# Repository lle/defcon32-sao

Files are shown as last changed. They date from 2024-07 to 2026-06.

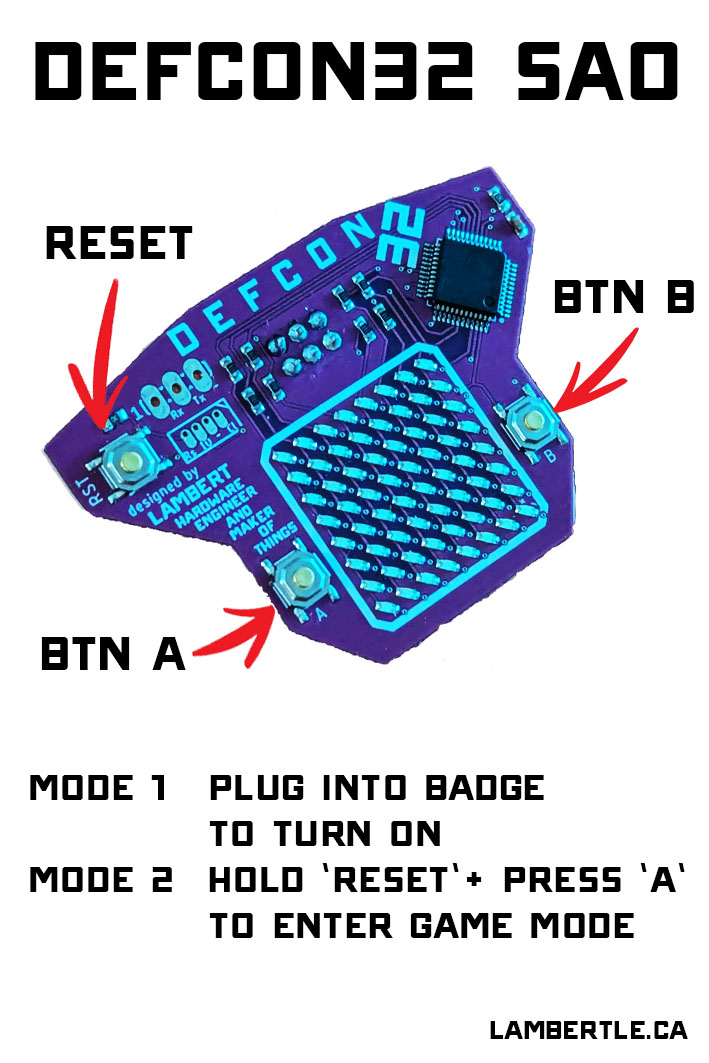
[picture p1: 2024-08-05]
media/defcon32-sao.jpg

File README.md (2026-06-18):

## Firmware Structure
See this readme in this repo: [SAO31](https://github.com/lle/defcon31-addon)
The foundation firmware is from my SAO from last year. This year's firmware adds an the Racing game mode in addition to the animation/screensaver mode.

## How to Flash
Things you need:
* ST-Link - I personally use an STM32F0 Nucleo Board: [497-15096-ND](https://www.digikey.ca/en/products/detail/stmicroelectronics/NUCLEO-F072RB/5047984)
* Female Connector: [H2193-ND](https://www.digikey.ca/en/products/detail/hirose-electric-co-ltd/DF13-4P-1-25DSA/241767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)
* Male Connector: [H2181-ND](https://www.digikey.ca/en/products/detail/hirose-electric-co-ltd/DF13-4S-1-25C/241750)
* Precrimped wires x4: [H4BXG-10112-B8-ND](https://www.digikey.ca/en/products/detail/hirose-electric-co-ltd/H4BXG-10112-B8/426117)

### Instruction
* Connect the ST-Link SWD header to the PCB's programming port
connection

* Compile the code in STM CubeIDE: "Project"->"Build All"
* Connect your Nucleo board to your computer
* Configure the debugger as follows: "Run" -> "Debug Configurations"
connection
* Flash the firmware: "Run" -> "Run"
* You will see this in the logs
```
Memory Programming ...
Opening and parsing file: ST-LINK_GDB_server_a15460.srec
  File          : ST-LINK_GDB_server_a15460.srec
  Size          : 21.34 KB 
  Address       : 0x08000000 
Erasing memory corresponding to segment 0:
Erasing internal memory sectors [0 21]
Download in Progress:
File download complete
Time elapsed during download operation: 00:00:01.454
Verifying ...
Download verified successfully 
Shutting down...
Exit.
```
https://github.com/lle/defcon31-addon

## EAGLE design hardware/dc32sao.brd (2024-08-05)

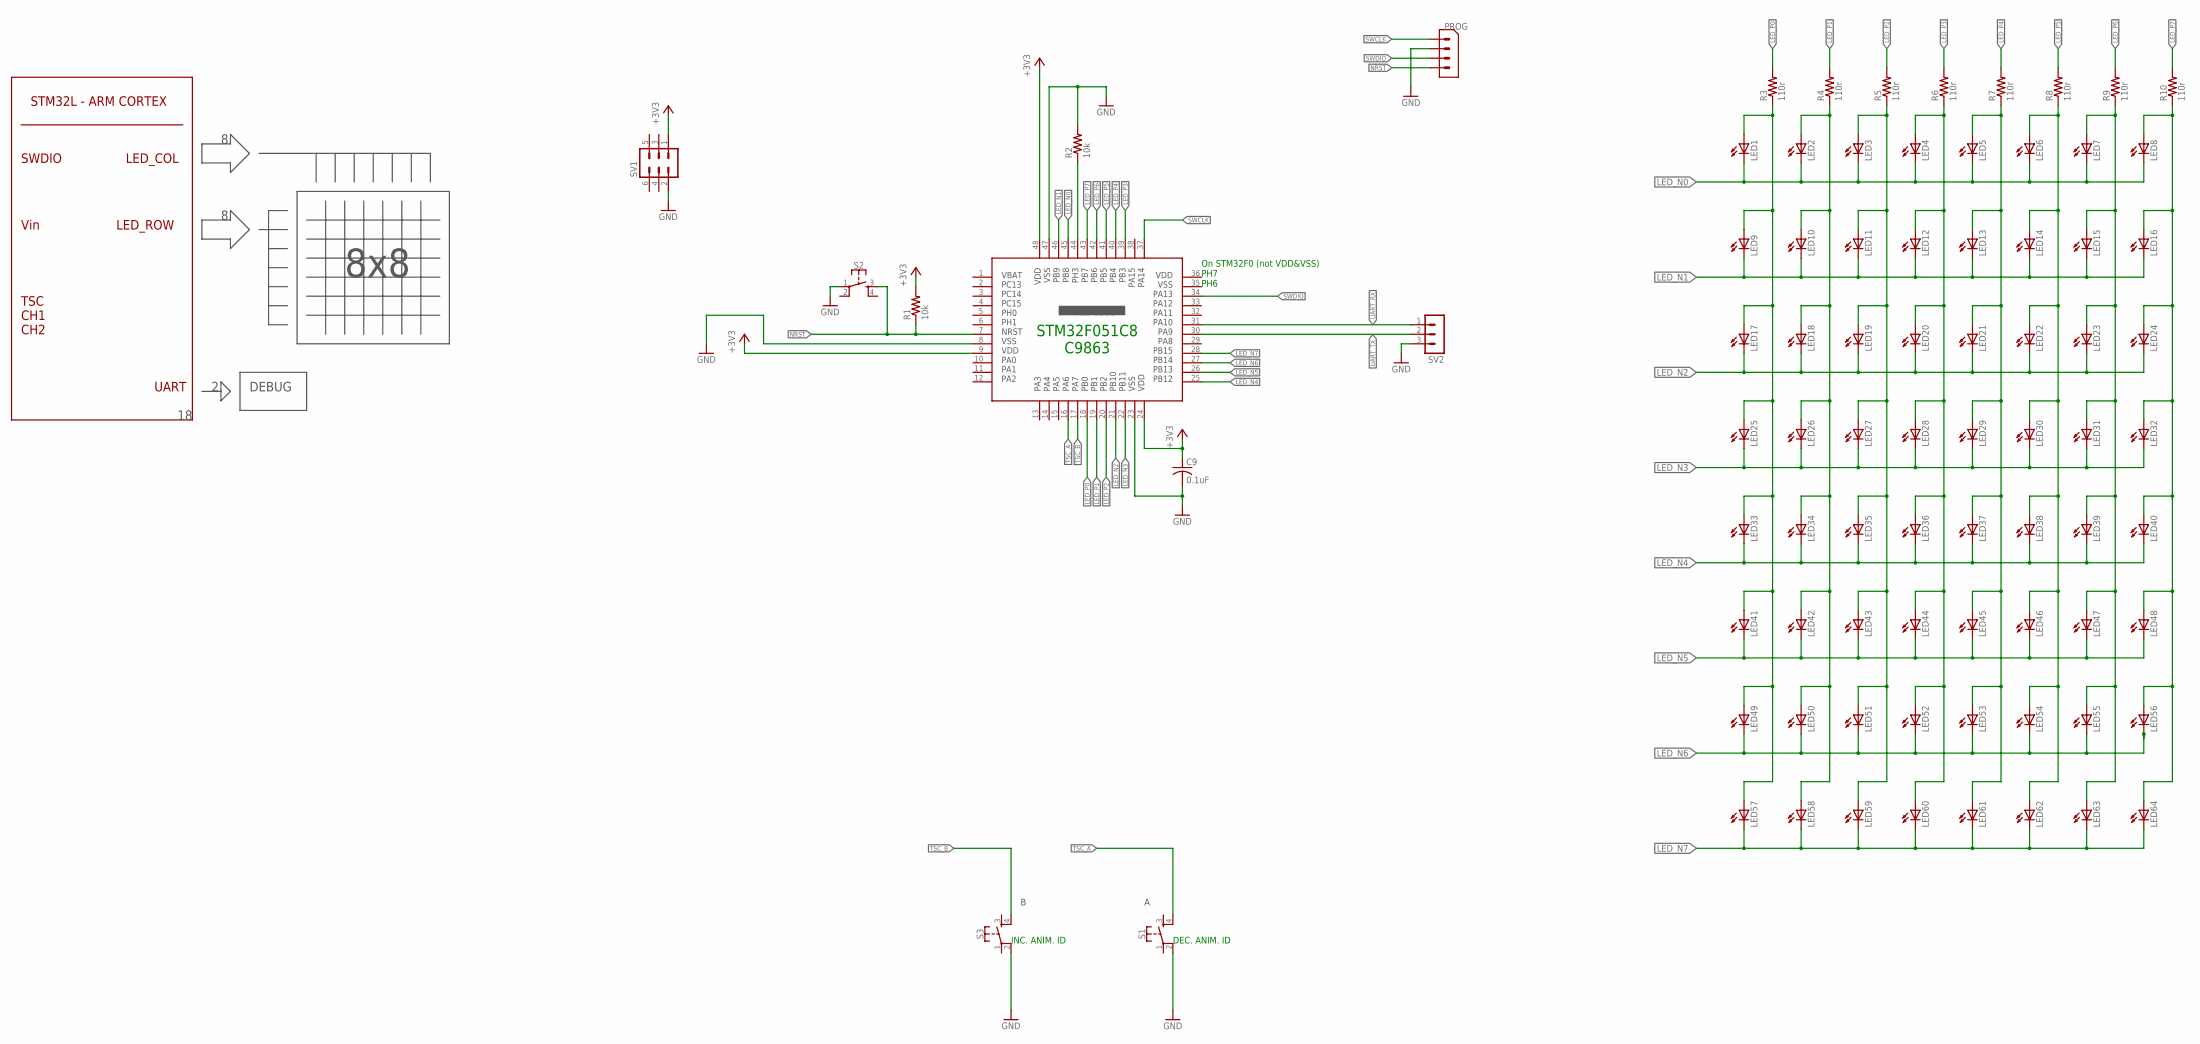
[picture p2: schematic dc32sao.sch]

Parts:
C9: 0.1uF; C0603
LED1, LED2, LED3, LED4, LED5, LED6, LED7, LED8, LED9, LED10, LED11, LED12, LED13, LED14, LED15, LED16, LED17, LED18, LED19, LED20, LED21, LED22, LED23, LED24, LED25, LED26, LED27, LED28, LED29, LED30, LED31, LED32, LED33, LED34, LED35, LED36, LED37, LED38, LED39, LED40, LED41, LED42, LED43, LED44, LED45, LED46, LED47, LED48, LED49, LED50, LED51, LED52, LED53, LED54, LED55, LED56, LED57, LED58, LED59, LED60, LED61, LED62, LED63, LED64: LEDCHIP-LED0603; CHIP-LED0603
PROG: 4-PIN-1.25MM
R1, R2: 10k; R0603
R3, R4, R5, R6, R7, R8, R9, R10: 110r; R0603
S1, S2, S3: MOMENTARY-SWITCH-SPST-2-SMD-5.2MM; TACTILE_SWITCH_SMD_5.2MM
SV1: MA03-2
SV2: MA03-1
U$2: STM32L431CC; QFP50P900X900X160-48

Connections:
+3V3: C9.1, R1.2, SV1.1, U$2.9, U$2.24, U$2.48
GND: C9.2, PROG.P$3 (2), R2.2, S1.2, S2.1, S3.2, SV1.2, SV2.3, U$2.8, U$2.23, U$2.47
LED_N0: LED1.C, LED2.C, LED3.C, LED4.C, LED5.C, LED6.C, LED7.C, LED8.C, U$2.45
LED_N1: LED9.C, LED10.C, LED11.C, LED12.C, LED13.C, LED14.C, LED15.C, LED16.C, U$2.46
LED_N2: LED17.C, LED18.C, LED19.C, LED20.C, LED21.C, LED22.C, LED23.C, LED24.C, U$2.21
LED_N3: LED25.C, LED26.C, LED27.C, LED28.C, LED29.C, LED30.C, LED31.C, LED32.C, U$2.22
LED_N4: LED33.C, LED34.C, LED35.C, LED36.C, LED37.C, LED38.C, LED39.C, LED40.C, U$2.25
LED_N5: LED41.C, LED42.C, LED43.C, LED44.C, LED45.C, LED46.C, LED47.C, LED48.C, U$2.26
LED_N6: LED49.C, LED50.C, LED51.C, LED52.C, LED53.C, LED54.C, LED55.C, LED56.C, U$2.27
LED_N7: LED57.C, LED58.C, LED59.C, LED60.C, LED61.C, LED62.C, LED63.C, LED64.C, U$2.28
LED_P0: R3.2, U$2.18
LED_P0B: LED1.A, LED9.A, LED17.A, LED25.A, LED33.A, LED41.A, LED49.A, LED57.A, R3.1
LED_P1: R4.2, U$2.19
LED_P1B: LED2.A, LED10.A, LED18.A, LED26.A, LED34.A, LED42.A, LED50.A, LED58.A, R4.1
LED_P2: R5.2, U$2.20
LED_P2B: LED3.A, LED11.A, LED19.A, LED27.A, LED35.A, LED43.A, LED51.A, LED59.A, R5.1
LED_P3: R6.2, U$2.39
LED_P3B: LED4.A, LED12.A, LED20.A, LED28.A, LED36.A, LED44.A, LED52.A, LED60.A, R6.1
LED_P4: R7.2, U$2.40
LED_P4B: LED5.A, LED13.A, LED21.A, LED29.A, LED37.A, LED45.A, LED53.A, LED61.A, R7.1
LED_P5: R8.2, U$2.41
LED_P5B: LED6.A, LED14.A, LED22.A, LED30.A, LED38.A, LED46.A, LED54.A, LED62.A, R8.1
LED_P6: R9.2, U$2.42
LED_P6B: LED7.A, LED15.A, LED23.A, LED31.A, LED39.A, LED47.A, LED55.A, LED63.A, R9.1
LED_P7: R10.2, U$2.43
LED_P7B: LED8.A, LED16.A, LED24.A, LED32.A, LED40.A, LED48.A, LED56.A, LED64.A, R10.1
unnamed: R2.1, U$2.44
NRST: PROG.P$1 (4), R1.1, S2.3, U$2.7
SWCLK: PROG.P$4 (1), U$2.37
SWDIO: PROG.P$2 (3), U$2.34
TSC_A: S1.4, U$2.16
TSC_B: S3.4, U$2.17
UART_RX: SV2.1, U$2.31
UART_TX: SV2.2, U$2.30

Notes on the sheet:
SWDIO
Vin
LED_COL
LED_ROW
TSC CH1 CH2
STM32L - ARM CORTEX
DEBUG
UART
8x8
STM32F051C8 C9863
On STM32F0 (not VDD&VSS) PH7 PH6
DEC. ANIM. ID
INC. ANIM. ID

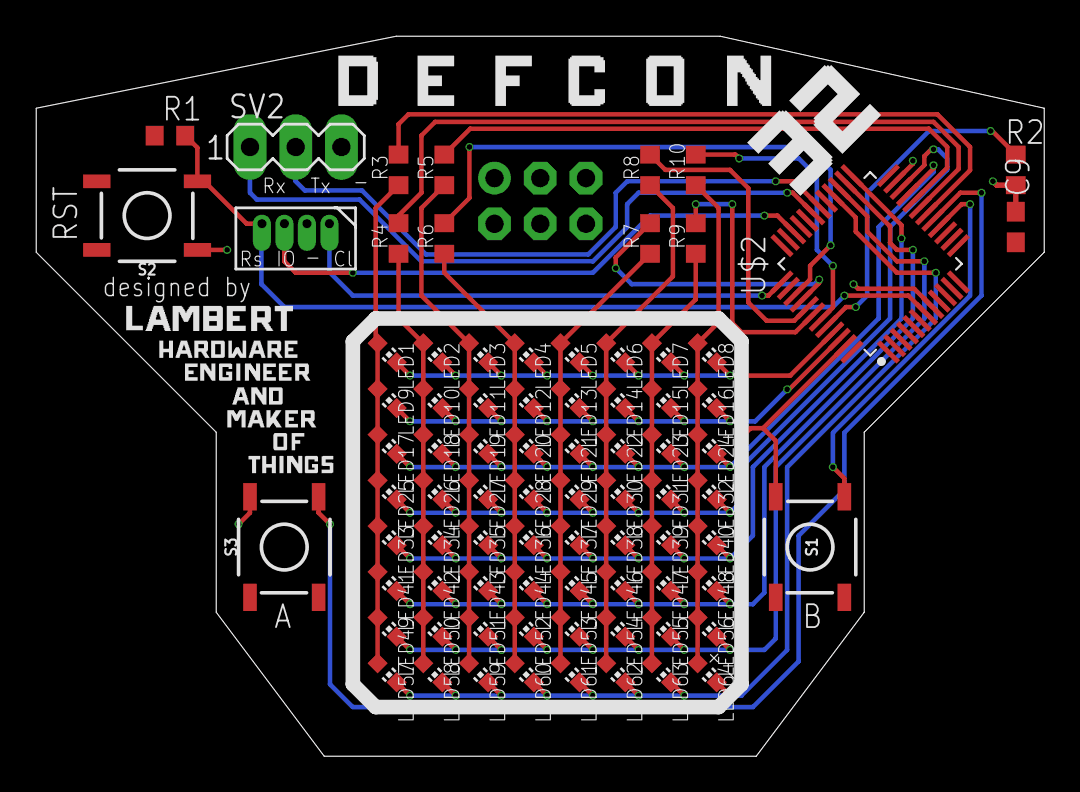
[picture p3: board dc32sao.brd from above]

Board: 2 copper layers, 56.0 x 40.0 mm, 82 parts (1 on the bottom side), 34 nets.

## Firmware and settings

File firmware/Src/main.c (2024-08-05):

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
/* Includes ------------------------------------------------------------------*/
#include "main.h"
#include "adc.h"
#include "tim.h"
#include "usart.h"
#include "gpio.h"

/* USER CODE BEGIN Includes */


#include "screenBuffer.h"
#include "ascii_letter.h"
#include "anim_random.h"
#include "anim_swipe.h"
#include "anim_name.h"
#include "anim_ball.h"
#include "anim_life.h"
#include "game_racer.h"

/* USER CODE END Includes */

/* USER CODE BEGIN PD */

#define MAX_ANIM_ID 10
#define DELAY_PER_LETTER 500
uint8_t currentAnimation = 1;

/* USER CODE END PD */


void SystemClock_Config(void);
/* USER CODE BEGIN 0 */

void animationSelector()
{
	static uint32_t schedulerTimestamp_updateName = 0;
	if( HAL_GPIO_ReadPin(BTB_GPIO_Port, BTB_Pin) == GPIO_PIN_RESET )
	{
		currentAnimation++;
		if(currentAnimation == MAX_ANIM_ID)
			currentAnimation = 0;

		//HAL_Delay(100);
		while(HAL_GPIO_ReadPin(BTB_GPIO_Port, BTB_Pin) == GPIO_PIN_RESET)
		{
			screen_show_letter((currentAnimation < 10)?(ASCII_ZERO + currentAnimation):(ASCII_UPPER_A + currentAnimation - 10));
			HAL_Delay(100);
		}
	}
	else if( HAL_GPIO_ReadPin(BTA_GPIO_Port, BTA_Pin) == GPIO_PIN_RESET )
	{
    if(currentAnimation == 0)
      currentAnimation = MAX_ANIM_ID-1;
    else
      currentAnimation--;

		//HAL_Delay(100);
		while(HAL_GPIO_ReadPin(BTA_GPIO_Port, BTA_Pin) == GPIO_PIN_RESET)
		{
			screen_show_letter((currentAnimation < 10)?(ASCII_ZERO + currentAnimation):(ASCII_UPPER_A + currentAnimation - 10));
			HAL_Delay(100);
		}
	}

	switch(currentAnimation)
	{
		 case 0:
			 anim_random_run();
			 break;
		 case 1:
			 if(HAL_GetTick() - schedulerTimestamp_updateName > DELAY_PER_LETTER)
			 {
				 schedulerTimestamp_updateName = HAL_GetTick();
				 anim_name_word("DEFCON32! ");
			 }
			 break;
		 case 2:
			 anim_horizontal_run();
			 break;
		 case 3:
			 anim_vertical_run();
			 break;
		 case 4:
			 anim_diagonal_run();
			 break;
		 case 5:
			 anim_rotate_run();
			 break;
		 case 6:
			 if(HAL_GetTick() - schedulerTimestamp_updateName > DELAY_PER_LETTER)
			 {
				 schedulerTimestamp_updateName = HAL_GetTick();
				 anim_name_word("RAWR! ^.^ ");
			 }
			 break;
		 case 7:
			 anim_swipeAll_run();
			 break;
		 case 8:
			 anim_ball_run();
			 break;
		 case 9:
			 anim_life_run();
			 break;
		 default:
			 screen_fill(); HAL_Delay(10);
			 screen_clear(); HAL_Delay(10);
			 break;
	}
}

/* USER CODE END 0 */

/**
  * @brief  The application entry point.
  * @retval int
  */
int main(void)
{

  /* MCU Configuration--------------------------------------------------------*/

  /* Reset of all peripherals, Initializes the Flash interface and the Systick. */
  HAL_Init();

  /* Configure the system clock */
  SystemClock_Config();

  /* Initialize all configured peripherals */
  MX_GPIO_Init();
  MX_USART1_UART_Init();
  MX_TIM16_Init();
  MX_ADC_Init();
  /* USER CODE BEGIN 2 */

  //Generate seed from floating ADC pin
  HAL_ADC_Start(&hadc);
  uint32_t seed = 0;
  uint32_t currentVal = 0;
  for(int i=0; i<10; i++)
  {
	  HAL_ADC_PollForConversion(&hadc, 0xFF);
	  currentVal = HAL_ADC_GetValue(&hadc);
	  seed = seed + currentVal;
	  HAL_Delay(2);
  }
  srand(seed);	//input seed into sRand

  //start timer for screen refresh
  HAL_TIM_Base_Start_IT(&htim16);

  // Initiate matrix for conway
  anim_life_setup();

  /* USER CODE END 2 */

  /* Infinite loop */
  /* USER CODE BEGIN WHILE */
  uint8_t gameSelector = 0;
  if( HAL_GPIO_ReadPin(BTB_GPIO_Port, BTB_Pin) == GPIO_PIN_RESET || HAL_GPIO_ReadPin(BTA_GPIO_Port, BTA_Pin) == GPIO_PIN_RESET ) //IF button is held during boot, enter different game mode
  {
	  gameSelector = 1;
  }
    /* USER CODE END WHILE */
    /* USER CODE BEGIN 3 */
  if(gameSelector == 1)
  {
	while(1)
		gameRacer_run();
  }
  else
  {
	while (1)
		animationSelector();
  }
  /* USER CODE END 3 */
}

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


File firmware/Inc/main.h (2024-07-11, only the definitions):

#define BTB_Pin GPIO_PIN_6
#define BTB_GPIO_Port GPIOA
#define BTA_Pin GPIO_PIN_7
#define BTA_GPIO_Port GPIOA
#define LED_P_0_Pin GPIO_PIN_0
#define LED_P_0_GPIO_Port GPIOB
#define LED_P_1_Pin GPIO_PIN_1
#define LED_P_1_GPIO_Port GPIOB
#define LED_P_2_Pin GPIO_PIN_2
#define LED_P_2_GPIO_Port GPIOB
#define LED_N_2_Pin GPIO_PIN_10
#define LED_N_2_GPIO_Port GPIOB
#define LED_N_3_Pin GPIO_PIN_11
#define LED_N_3_GPIO_Port GPIOB
#define LED_N_4_Pin GPIO_PIN_12
#define LED_N_4_GPIO_Port GPIOB
#define LED_N_5_Pin GPIO_PIN_13
#define LED_N_5_GPIO_Port GPIOB
#define LED_N_6_Pin GPIO_PIN_14
#define LED_N_6_GPIO_Port GPIOB
#define LED_N_7_Pin GPIO_PIN_15
#define LED_N_7_GPIO_Port GPIOB
#define LED_P_3_Pin GPIO_PIN_3
#define LED_P_3_GPIO_Port GPIOB
#define LED_P_4_Pin GPIO_PIN_4
#define LED_P_4_GPIO_Port GPIOB
#define LED_P_5_Pin GPIO_PIN_5
#define LED_P_5_GPIO_Port GPIOB
#define LED_P_6_Pin GPIO_PIN_6
#define LED_P_6_GPIO_Port GPIOB
#define LED_P_7_Pin GPIO_PIN_7
#define LED_P_7_GPIO_Port GPIOB
#define LED_N_0_Pin GPIO_PIN_8
#define LED_N_0_GPIO_Port GPIOB
#define LED_N_1_Pin GPIO_PIN_9
#define LED_N_1_GPIO_Port GPIOB

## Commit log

2024-07-10 working raceCar prototype
    - todo: collision detection
    - make sure two obstacle are not side by side
    [defcon32.ioc, game_racer.c, main.c]
2024-07-10 collision algo implemented
    todo: enabled 2nd button and map it
    [game_racer.c]
2024-07-11 Alpha firmware completed
    - added #define for better clarity
    - migrated to latest HAL drivers
    - added 2nd button
    - fixed edge case for collision detection during wrap around
    TODO: test on actual hardware
    [defcon32.ioc, game_racer.c, main.c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]
2024-07-22 Updated button behavior
    - animation ID starts from ZERO in the UI
    - animation start with ID = 1 ("defcon32")
    - fixed button left/right
    - added btn_a to enter into racegame during boot
    [game_racer.c, main.c]
2024-08-05 firmware tweaking + published hardware design
    - improved racing game behavior for better UX
    - fixed animation increment/decrement on button press
    - published the hardware design
    - added pictures assets to repo
    [dc32sao.brd, dc32sao.sch]

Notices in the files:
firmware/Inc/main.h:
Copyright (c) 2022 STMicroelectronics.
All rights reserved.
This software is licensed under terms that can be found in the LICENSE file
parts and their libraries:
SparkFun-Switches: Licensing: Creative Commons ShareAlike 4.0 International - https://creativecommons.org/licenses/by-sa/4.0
